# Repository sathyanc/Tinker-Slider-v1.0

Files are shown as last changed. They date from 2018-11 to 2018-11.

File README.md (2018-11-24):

# Tinker-Slider-v1.0

I have never seen a commercial slider. As a YouTuber, I wanted a Camera slider for taking b-rolls for my videos. So as a weekend project I started this project, and it took several weekends to complete. 

The following parts were used to build the single axis slider. 

1.M3 and M4 Machine Screw Box
2.Tripod Mount 1/4 Screw Adapter x 2
3.Tripod Mount Screw
4.Linear Motion Bearing x 4
5.Heat shrink tubes
6.Endstop modules x 2 
7.GT2 6mm, 2M timing belt
8.ESP32 NodeMcu Dev board
9.A4988 Stepper motor
10.Perf board
11.Male and Female Headers
12.SD1306 128x64 OLED display module
13.Belt tensioner spring
14.Rotary encoder
15.Linear, smooth rods 8mm, 500mm x 2
16.Wire Pipe 480mm
17.Linear Rail supports x 4

At the heart of the project sits the ESP32 microcontroller. Initially, I tried with ESP8266, but there were not enough pins, and then I tried with Arduino Pro Mini, but then the memory was minimal to use the LCD. 

The ESP32 runs Arduino Core. 

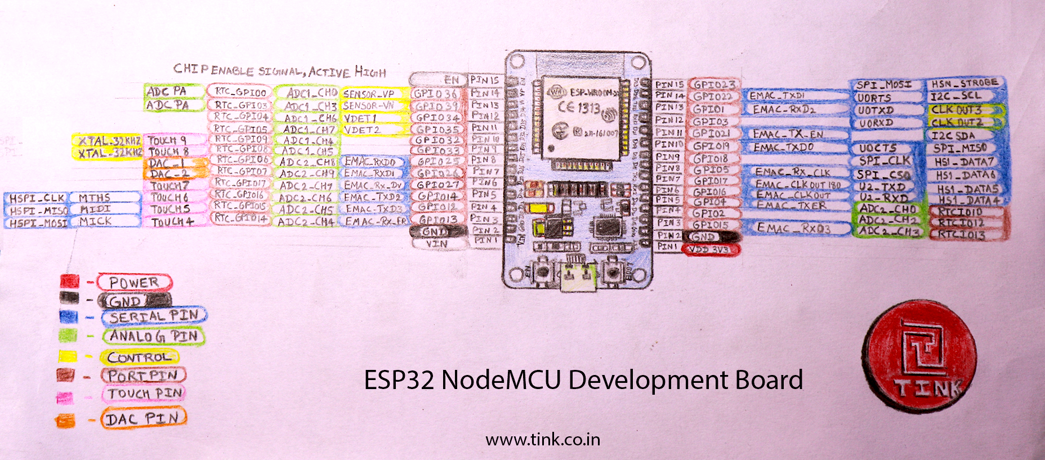
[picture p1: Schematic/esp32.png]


I used a 2 phase NEMA17 Hybrid motor that has a holding torque of 4000. The motor needs 1.7A per phase. It has a resolution of 1.8 degrees per step.  So to complete a single revolution, we need to step the motor 200 times. However, we need the resolution as low as 1 degree per step to be able to capture the super smooth moving time-lapse videos. 

The ESP32 Controls the stepper motor through the A4988 Stepper motor driver chip. This driver chip supports up to 1/16th  Microstepping mode which enables us to achieve rotational accuracy up to 0.0625degrees per step.

Awesome!

The SSD1306 0.96" OLED display module enables us to see an configure the display even under bright sunlight.

The Rotary Encoder can be used to precisely control the position of the motor and also as a selection tool for the menu. Several Modes like manual and automatic time-lapse, real-time control, tried and tested presets to shoot flowers, people, gadgets are supported.

Libraries required:
Accelstepper - https://github.com/adafruit/AccelStepper
Adafruit GFX - https://github.com/adafruit/Adafruit-GFX-Library
Adafruit SSD1306 - https://github.com/adafruit/Adafruit_SSD1306

References:
https://github.com/Wogified/Arduino-Motorized-Camera-Slider

To-Do:
WiFi Control by App / Custom Remote,
3 Axis Conversion,
CNC Milled Design

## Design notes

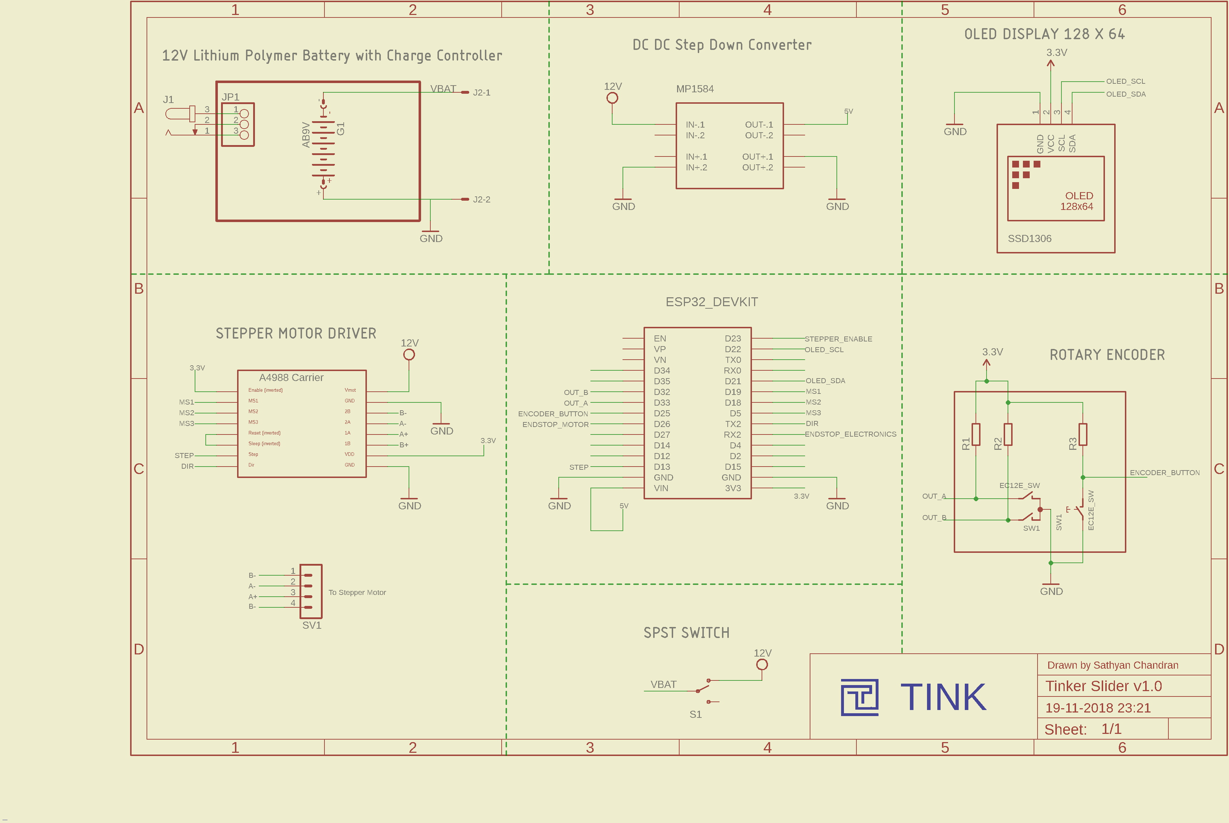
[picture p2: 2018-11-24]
Schematic/tinkerslider.png

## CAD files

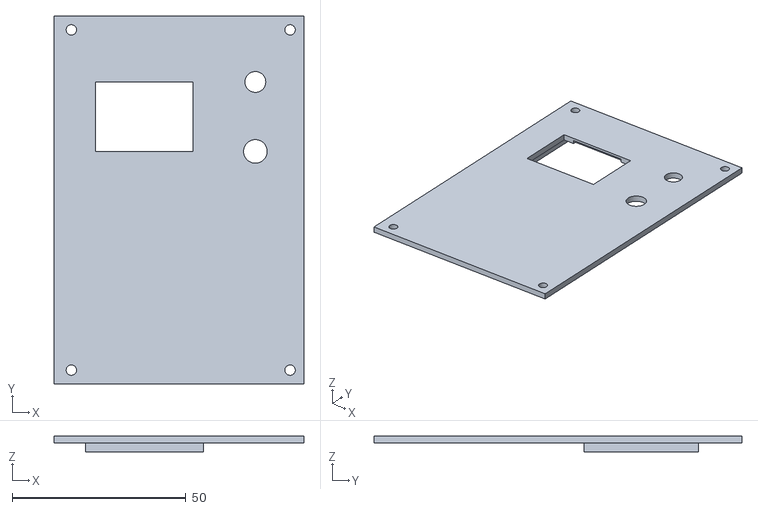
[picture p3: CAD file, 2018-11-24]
3D_Models/electronics lid v2.12.stl
72.0 x 106.0 x 4.50

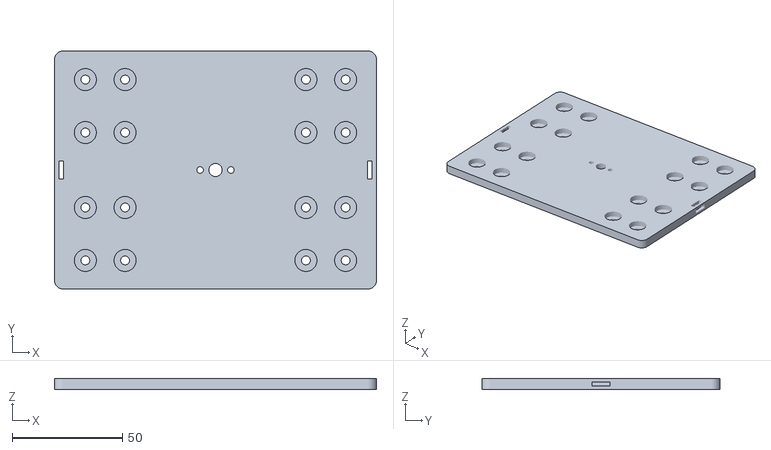
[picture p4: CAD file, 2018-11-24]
3D_Models/cam plate 4 bearings.stl
146.0 x 108.0 x 5.00

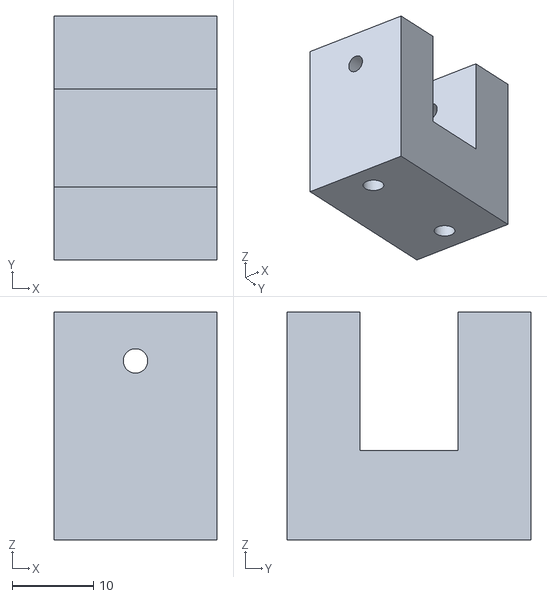
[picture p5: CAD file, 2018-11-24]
3D_Models/idle pulley holder.stl
20.0 x 30.0 x 28.0

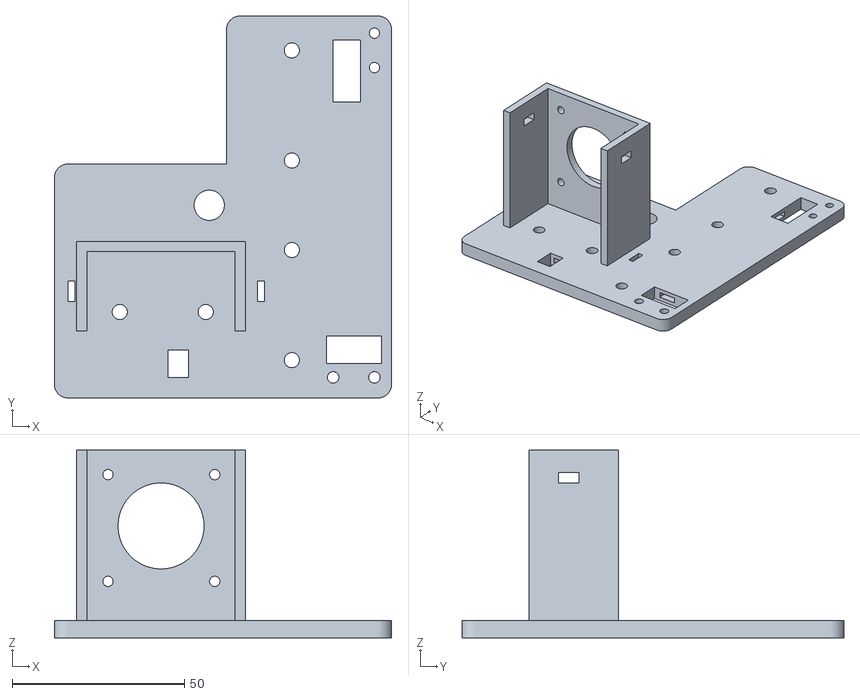
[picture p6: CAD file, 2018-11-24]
3D_Models/motor side base.stl
98.0 x 111.0 x 54.5

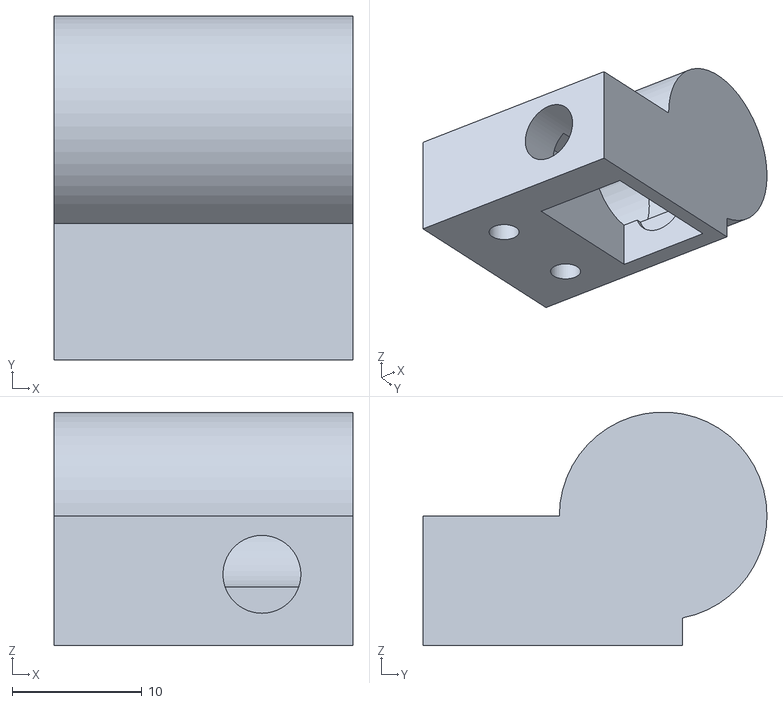
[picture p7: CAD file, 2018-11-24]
3D_Models/electronics_side_pipe_holder.stl
23.0 x 26.5 x 18.0

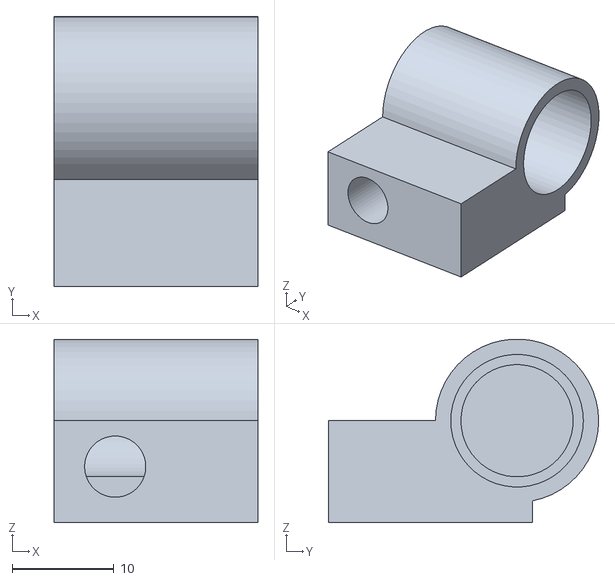
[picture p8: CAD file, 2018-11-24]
3D_Models/motor_side_pipe_holder.stl
20.0 x 26.5 x 18.0

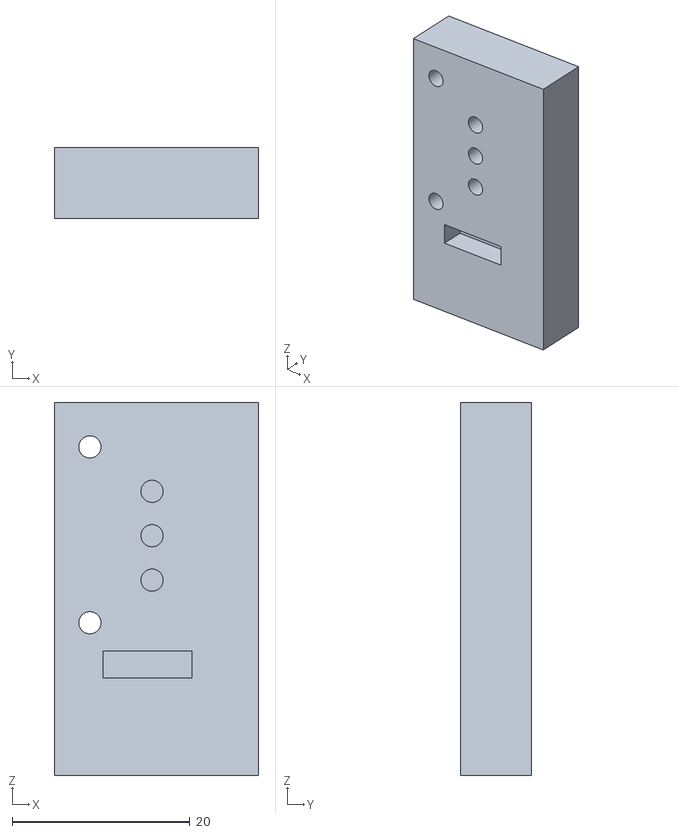
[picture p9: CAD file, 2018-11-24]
3D_Models/electronics endstop.stl
23.0 x 8.00 x 42.0

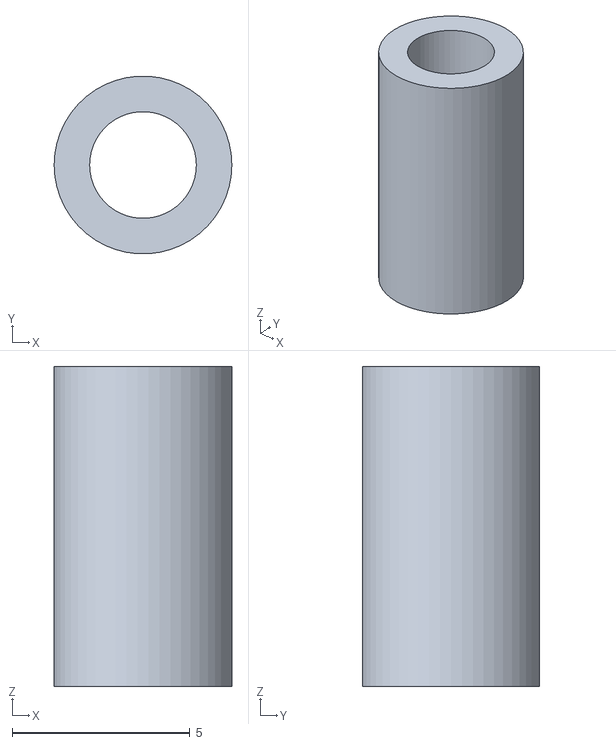
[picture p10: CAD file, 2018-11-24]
3D_Models/idle pulley bearing cylinder.stl
5.00 x 4.99 x 9.00

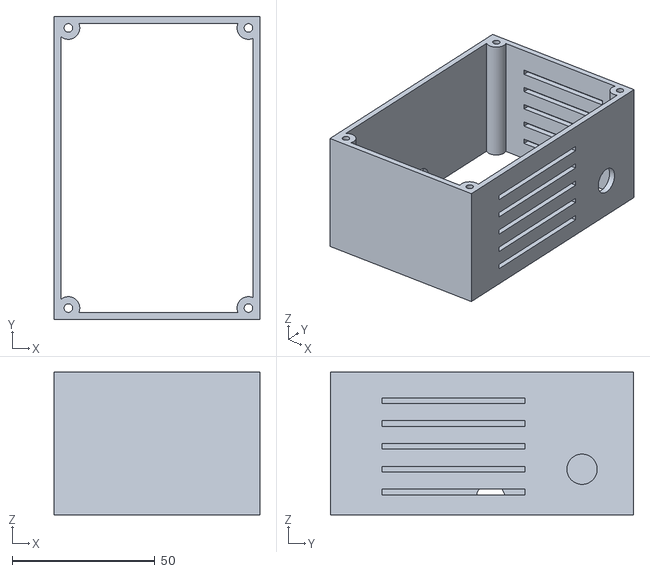
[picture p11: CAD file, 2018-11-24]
3D_Models/electronics box.stl
72.0 x 106.0 x 50.0

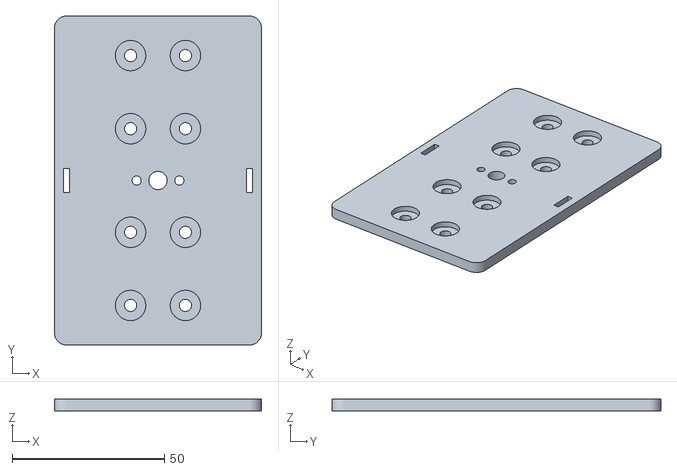
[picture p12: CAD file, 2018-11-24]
3D_Models/cam plate 2 bearings.stl
68.0 x 108.0 x 4.00

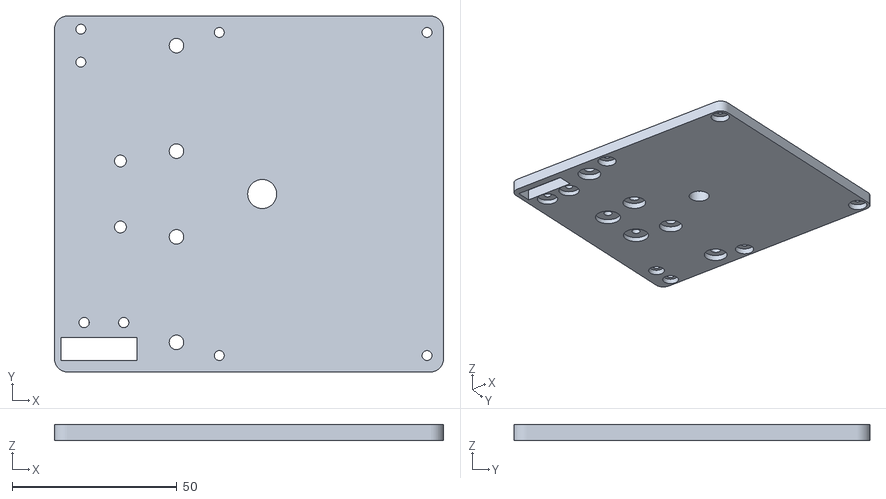
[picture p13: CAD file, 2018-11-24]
3D_Models/electronics base.stl
118.0 x 108.0 x 5.00

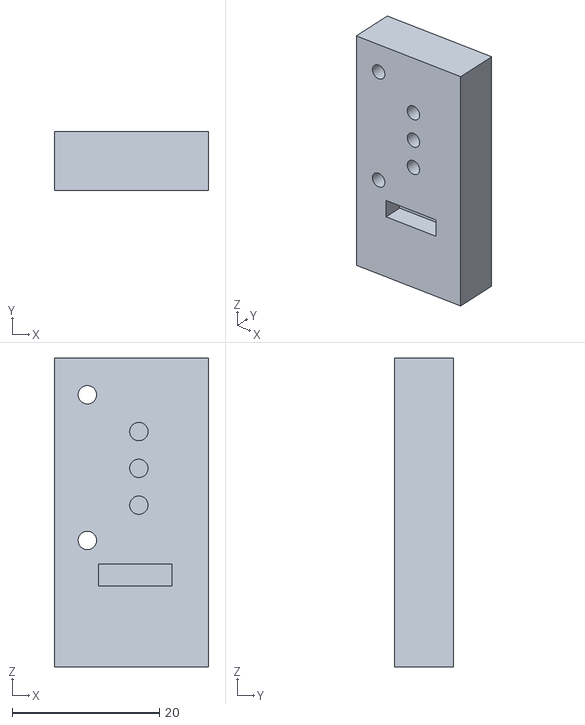
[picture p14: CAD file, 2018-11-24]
3D_Models/motor endstop.stl
21.0 x 8.00 x 42.0

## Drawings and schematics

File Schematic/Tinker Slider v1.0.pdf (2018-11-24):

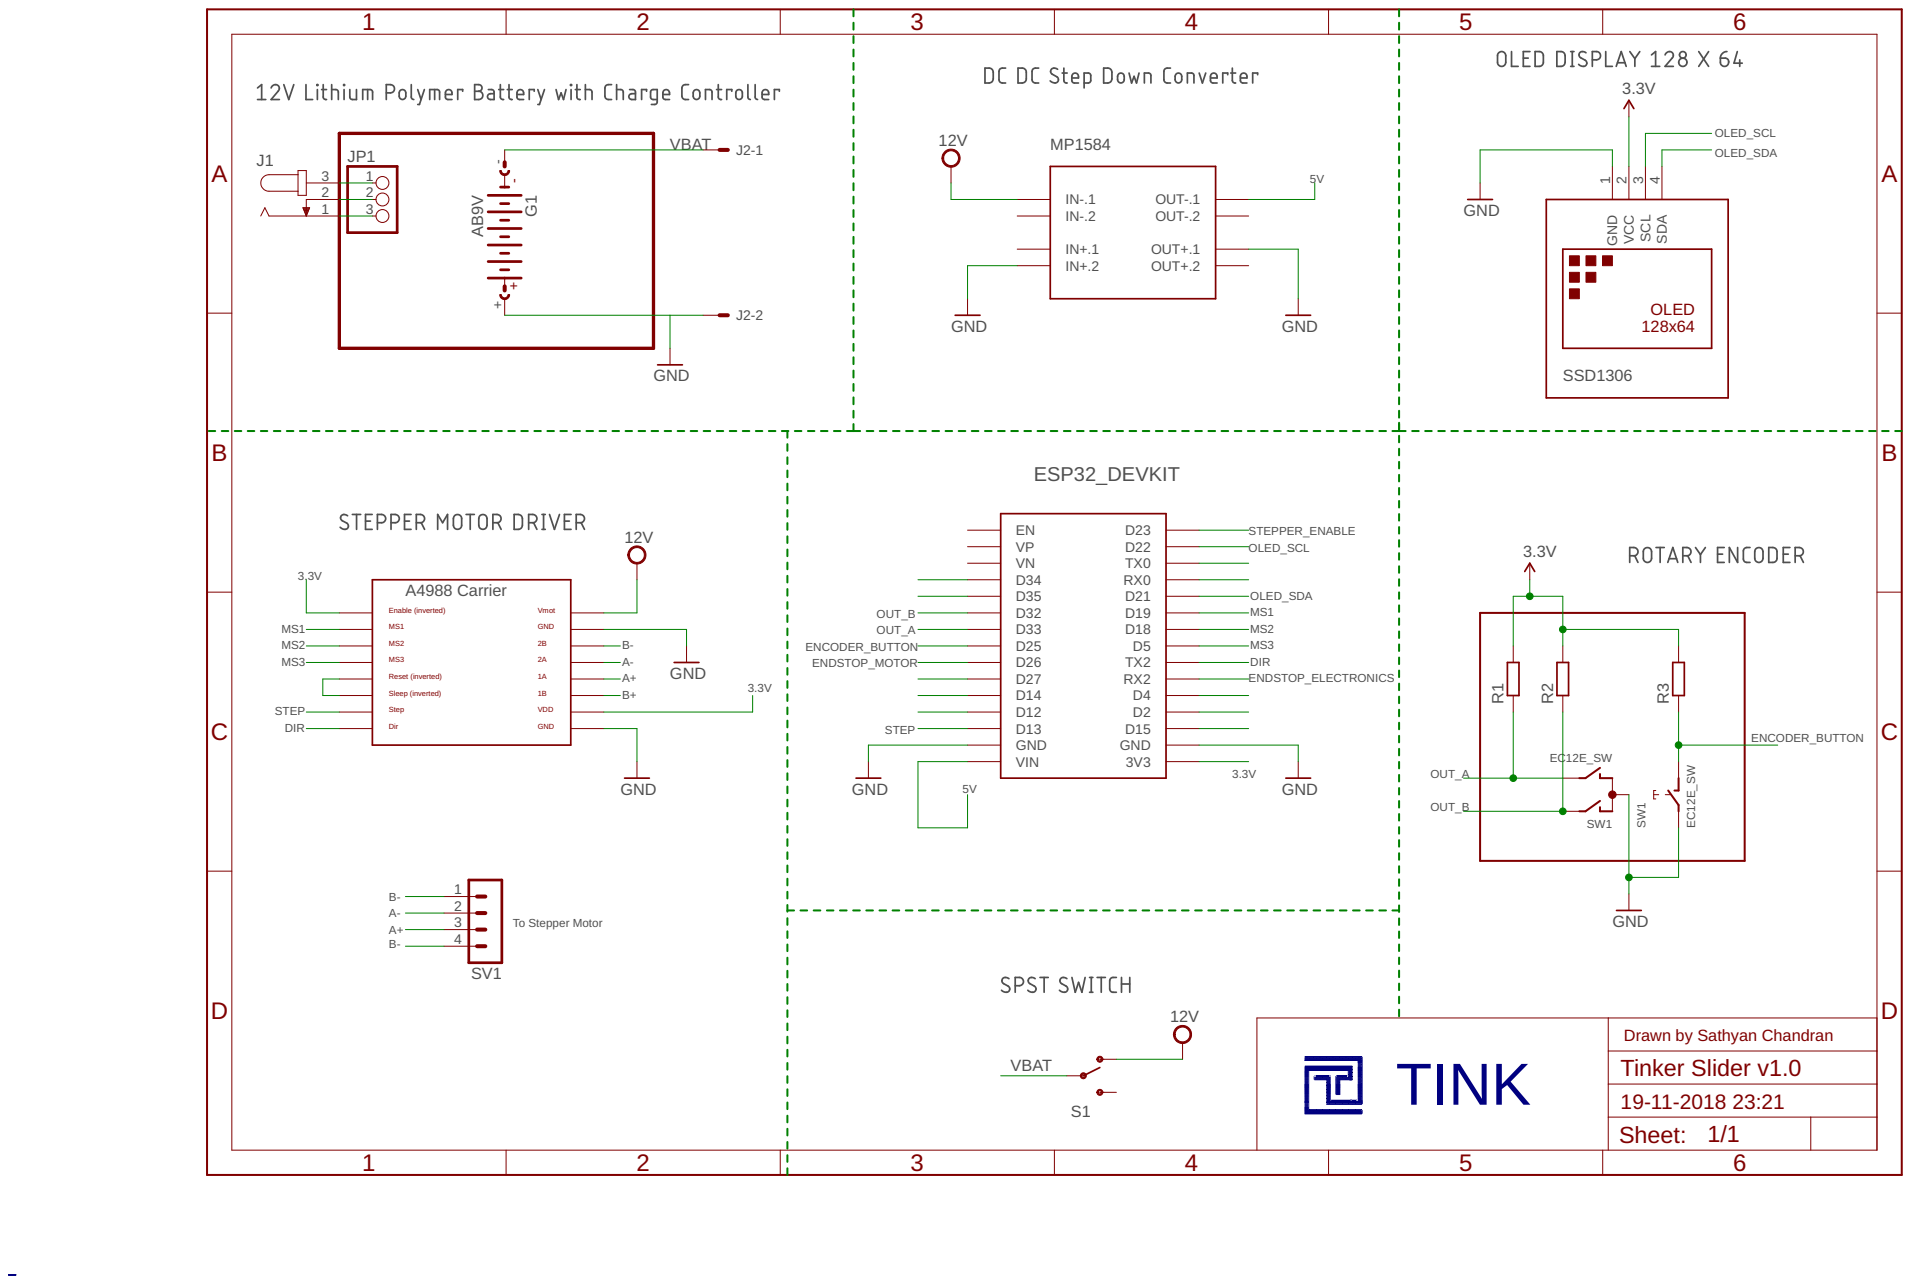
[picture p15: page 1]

TINK

Sheet: 1/1

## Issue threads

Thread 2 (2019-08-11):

New to ESP32, first project

diegotheslinger, 2019-08-11:
Hey, i've built a simple timelapse slider in the past based on atmel328, and was looking to expand some of its features.  Found your project and had an ESP32 laying around.  First time trying to use one.  I get it to compile and upload fine, but am getting errors in serial monitor.

Tinker Slider V1.0!!
Guru Meditation Error: Core  1 panic'ed (IntegerDivideByZero). Exception was unhandled.

I'm new to this, any tip on how to overcome this?  Maybe library issue?

Electoniclover, 2022-05-23:
I don't have a ti[ but i need help

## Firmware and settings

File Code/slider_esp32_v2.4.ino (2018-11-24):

// Runs on ESP32 Arduino. 
// To Do: Add WiFi controls


#include <SPI.h>
#include <Wire.h>
#include <Adafruit_GFX.h>
#include <Adafruit_SSD1306.h>
#include "AccelStepper.h" 

//Endstops
#define endstopMotor 26
#define endstopElectronics 16

//Stepper  
#define STEPPER_ENABLE 23
#define MS1 19
#define MS2 18
#define MS3 5
#define DIR 17
#define STEP 13

AccelStepper stepper(1, STEP, DIR); 

//Debug 
#define BAUD_RATE (9600)

//Display
#define OLED_RESET LED_BUILTIN 
#define LOGO16_GLCD_HEIGHT 16 
#define LOGO16_GLCD_WIDTH  16 

Adafruit_SSD1306 display(OLED_RESET);

//Encoder
#define encButton 25 
#define outA 33 
#define outB 32 

int outA_lastState,outA_currentState,counter=0;
int selection=1;
int numCount=1;
int encoderState;
int encoderLastState;  

volatile byte seqA = 0;
volatile byte seqB = 0;
volatile byte cnt1 = 0;
volatile byte cnt2 = 0;
volatile boolean right = false;
volatile boolean left = false;
volatile boolean encButtonStatus = false;


void IntCallback();
void EncButtonStatusInt();
void MainMenu(int selection);
void RealTime();
void FixedTime();
void Flowers();
void People();
void Review();
void Quick();
void TimeSlide(float tim);
void ManualTimeLapse();
void SlideRealTime(int def);
void TimeLapse();
void SetTimerTimeLapse();
void MainMenuFixedTime(int selection);
void MainMenu(int selection);


void setup() 
{
  Serial.begin(115200);
  Serial.println("Tinker Slider V1.0!!");

  //Status
  pinMode(LED_BUILTIN,OUTPUT);

  //Stepper Driver
  pinMode(STEP,OUTPUT); 
  pinMode(DIR,OUTPUT); 
  pinMode(STEPPER_ENABLE,OUTPUT);
  pinMode(MS1,OUTPUT);
  pinMode(MS2,OUTPUT);
  pinMode(MS3,OUTPUT);
  
  digitalWrite(STEPPER_ENABLE,LOW);
  
  // Set in 1/16th microstep mode
  digitalWrite(MS1,HIGH);
  digitalWrite(MS2,HIGH);
  digitalWrite(MS3,HIGH); 

  
  //Encoder
  pinMode(outA,INPUT_PULLUP);
  pinMode(outB,INPUT_PULLUP);
  pinMode(encButton,INPUT_PULLUP);
  digitalWrite(outA,HIGH);
  digitalWrite(outB,HIGH);
  digitalWrite(encButton,HIGH);

  //Interrupt Enable
  attachInterrupt(digitalPinToInterrupt(outA), IntCallback, CHANGE);
  attachInterrupt(digitalPinToInterrupt(outB), IntCallback, CHANGE);
  attachInterrupt(digitalPinToInterrupt(encButton), EncButtonStatusInt, CHANGE);
  
  //Endstop
  pinMode(endstopElectronics,INPUT_PULLUP);
  pinMode(endstopMotor,INPUT_PULLUP);
  digitalWrite(endstopElectronics,HIGH);
  digitalWrite(endstopMotor,HIGH);    
  
  //Display
  display.begin(SSD1306_SWITCHCAPVCC, 0x3C);  
  
  //Display the Tink splashscreen based on Adafruit GFX library
  display.display();  
  delay(1000);         
}

void loop() 
{ 
  MainMenu(ScrollSelection(3));  
}


void MainMenu(int selection)//main menu
{
  encButtonStatus=true;
  int numItems=3;

  Serial.println("Menu Select");
  display.clearDisplay();
  display.setTextSize(1);
  display.setTextColor(WHITE);
  display.setCursor(0,0);
  display.println("Tinker Slider v1.0");
  display.drawLine(0,15-1,127,15-1,WHITE);
  display.drawLine(0,16-1,127,16-1,WHITE);
  
  String MainMenu[] = {"1. RealTime","2. TimeLapse","3. FixedTime"};
  DisplayMenuSelection(numItems,MainMenu);
 
  
  if(encButtonStatus == false)
  {
    Serial.println("encButtonStatus Pressed");
    delay(500); // time delay to ensure encButtonStatus is released
    digitalWrite(encButton,HIGH);
    encButtonStatus=true;//set encButtonStatus state to false, otherwise it will remain true. it is toggle.
    switch(selection)
    {
      Serial.print("selection:");
      Serial.println(selection);
      case 1:
        RealTime();
        break;
      case 2:
        TimeLapse();  
        break;
      case 3:
        FixedTime();
        break;
      default:
        Serial.println("No such Menu");
        break;
    }      
  }
  
}


void MainMenuFixedTime(int selection)//main menu
{
  encButtonStatus=true;
  int numItems=4;
  
  display.clearDisplay();
  display.setTextSize(1);
  display.setTextColor(WHITE);
  display.setCursor(0,0);
  display.println("Fixed Time Mode");
  display.drawLine(0,15-1,127,15-1,WHITE);
  display.drawLine(0,16-1,127,16-1,WHITE);
  
  String MainMenu[] = {"1. Flowers ","2. People","3. Review","4. Quick!"};
  DisplayMenuSelection(numItems,MainMenu);

  //if the encoder encButtonStatus is pressed, then selection is made (through interrupts)
  if(encButtonStatus == false)
  {
    Serial.println("Button Pressed");
    delay(500); // time delay to ensure encButtonStatus is released
    digitalWrite(encButton,HIGH);
    encButtonStatus=true;  
    switch(selection)
    {
      Serial.print("selection:");
      Serial.println(selection);
      case 1:
        Flowers();    // Contains the tried and tested sliding time to capture flowers
        break;
      case 2:
        People();     // Contains the tried and tested sliding time to capture people
        break;
      case 3:
        Review();     // Contains the tried and tested sliding time to review products (Accelerated)
        break;
      case 4:
        Quick();      // A 5 sec quick slide!
        break;
      default:
        Serial.println("No such Menu");
        break;
    }      
  }
  
}



void SetTimerTimeLapse()
{
  
    int hr=0,mins=0,sec=0;
    char hrs[3],minutes[3],seconds[3];
    int timePlaceHolder = 0; 
    float timeVal = 0;
    
    // Prepare the display
    display.clearDisplay();
    display.setTextSize(1);
    display.setTextColor(WHITE);
    display.setCursor(0,0);
    
    display.println("Set the Timer!");
    display.setCursor(0,20);
    display.println("H : M : S");
    
    display.setTextColor(WHITE,BLACK);
    display.setCursor(0,36);

    //Display the time placeholders
    display.print(hr);
    display.print("   ");
    display.print(mins);
    display.print("   ");
    display.print(sec);

    display.setTextColor(BLACK,WHITE);
    display.setCursor(0,36);
    display.print("0");

    //Update the display
    display.display();
    
    encButtonStatus =true;
    counter = 0;
    encoderLastState = digitalRead(outA);

    while(1)
    {    
       encoderState = digitalRead(outA); // Reads current state of the outA
       if(encoderState != encoderLastState)
       { 
        if(timePlaceHolder==0)//hr
        {
        
         // clockwise if the outB state is different to the outA state
         if (digitalRead(outB) != encoderState)  hr++;
         else hr--;
         
         if(hr <=0) hr=0;  

         Serial.print("hr: ");
         Serial.println(hr);

         //Print the change on the display 
         sprintf((char*)hrs,"%-2d",hr);
         display.setTextColor(BLACK,WHITE);
         display.setCursor(0,36);
         display.print(hrs);
         
       }          

       if(timePlaceHolder==1)//Min
       {
         // clockwise if the outB state is different to the outA state
         if (digitalRead(outB) != encoderState) mins++;
         else mins--;
         
         if (mins <=0) mins =0;
                    
         Serial.print("mins: ");
         Serial.println(mins);
         
         //Print the change on the display 
         sprintf((char*)minutes,"%-2d",mins);
         display.setTextColor(BLACK,WHITE);
         display.setCursor(22,36);
         display.print(minutes);
       }

       
       if(timePlaceHolder==2)//Sec
       {
         // clockwise if the outB state is different to the outA state
         if (digitalRead(outB) != encoderState)  sec++;
         else  sec--;
         if (sec <= 0) sec=0;
         
         Serial.print("sec: ");
         Serial.println(sec);

         //Print the change on the display 
         sprintf((char*)seconds,"%-2d",sec);
         display.setTextColor(BLACK,WHITE);
         display.setCursor(44,36);
         display.print(seconds);
        }
        //Update the display
        display.display();    
       }    
       

       //Confirm the selection if the encoder encButtonStatus is pressed
       if(encButtonStatus== false)  
       {
        counter=0;
        delay(500); //Debounce

        //If hour Set, then highlight seconds placeholder 
        if(timePlaceHolder==0)
        {
          display.setTextColor(WHITE,BLACK);
          display.setCursor(0,36);
          display.print(hrs);

          display.setTextColor(BLACK,WHITE);
          display.setCursor(22,36);
          display.print("0");

        
        }
        //If mins Set, then highlight seconds placeholder
        else if(timePlaceHolder==1)
        {
         
          display.setTextColor(WHITE,BLACK);
          display.setCursor(22,36);
          display.print(minutes);

          display.setTextColor(BLACK,WHITE);
          display.setCursor(44,36);
          display.print("0");
        }

        // Time set
        else if(timePlaceHolder==2)
        {
          
          display.setTextColor(BLACK,WHITE);
          display.setCursor(44,36);
          display.print(seconds);
          display.display();    
          break;
        }
          
        timePlaceHolder++; 
       
        encoderState &= ~encoderState;    // Trigger the selection for the next option        
        encButtonStatus =true;
        digitalWrite(encButton,HIGH);
        display.display();                     
       }       
      }                       
      
      Serial.println("Time set");
      Serial.print("Hr:");
      Serial.print(hr);
      Serial.print("Mins");
      Serial.print(mins);
      Serial.print("Secs");
      Serial.print(sec);
      Serial.println(); 
        

      timeVal = sec + (mins * 60) + (hr*60*60); // calculate the time in secs
      Serial.println("Time in Seconds:");
      Serial.println(timeVal);

      // Bring the cam plate to home (Electronics Side endstop)
      homePosition();
      
      // Display the choosen Time in Seconds   
      display.clearDisplay();
      display.setTextSize(1);
      display.setTextColor(WHITE);
      display.setCursor(0,0);
      display.println("Timer Set!");
      display.drawLine(0,15-1,127,15-1,WHITE);
      display.drawLine(0,16-1,127,16-1,WHITE);
      display.setCursor(0,30);
      display.println("You have choosen");
      display.setCursor(12,40);
      display.print(timeVal);
      display.setCursor(68,40);
      display.print("Seconds");
      display.display();
    
      // Start the sliding for the timeVal seconds
      TimeSlide(timeVal);
}


// TimeLapse menu
void TimeLapse()
{
  selection =1;
  while(1)
  {  
    int selection = ScrollSelection(2);
    encButtonStatus=true;
    int numItems=2;
    
    Serial.println("Menu Select");
    display.clearDisplay();
    display.setTextSize(1);
    display.setTextColor(WHITE);
    display.setCursor(0,0);
    display.println("TimeLapse Modes");
    display.drawLine(0,15-1,127,15-1,WHITE);
    display.drawLine(0,16-1,127,16-1,WHITE);

    
    String MainMenu[] = {"1. Manual Adjust","2. Set Timer"};
    DisplayMenuSelection(numItems,MainMenu);
   
    
    if(encButtonStatus == false)
    {
      Serial.println("Button Pressed");
      delay(500); // debounce
      digitalWrite(encButton,HIGH);
      encButtonStatus=true;
      switch(selection)
      {
        Serial.print("selection:");
        Serial.println(selection);
        case 1:
          ManualTimeLapse();
          break;
        case 2:
          Serial.println("Set Timer");
          SetTimerTimeLapse();
          break;
      }      
    }
  }
}

// Manually adjust the time based on the encoder value
void ManualTimeLapse()
{
  Serial.println("In TimeLapse");
  
  homePosition();
  SlideRealTime(1);
  
}

// Used by Realtime slider 
void SlideRealTime(int def)
{  
  display.clearDisplay();
  display.setTextSize(1);
  display.setTextColor(WHITE);
  display.setCursor(0,0);
  display.println("Rotate the Knob Now!");
  display.setTextColor(WHITE,BLACK);
  display.setCursor(0,40);
  display.println("   Push to go Back!");
  display.display();
  delay(500);
  
  encoderLastState = digitalRead(outA); 
  stepper.enableOutputs(); 
  stepper.setMaxSpeed(4000);
  
  while(1)
  {
     encoderState = digitalRead(outA); 
     if (encoderState != encoderLastState)
     {     
       if (digitalRead(outB) != encoderState) 
         counter --;
       else 
         counter ++;
       Serial.print("Position: ");
       Serial.println(counter);
     } 
    
     
     stepper.setSpeed(def*counter);
     stepper.runSpeed(); 

     delayMicroseconds(1000);
           
     if(checkButtonStates() != 0)
      break;

      encoderLastState = encoderState; 
 } 
}


void Flowers()
{
  digitalWrite(MS1,HIGH);
  digitalWrite(MS2,HIGH);
  digitalWrite(MS3,HIGH); 
   
  homePosition();
  
  digitalWrite(MS1,HIGH);
  digitalWrite(MS2,HIGH);
  digitalWrite(MS3,LOW);
  
  stepper.setCurrentPosition(0);
  stepper.setMaxSpeed(1000);
  stepper.setAcceleration(500);
  stepper.moveTo(11200);  // Lets move upto 280mm which is required to complete the full slide
  
  while (stepper.currentPosition() != 11200) 
  {
     stepper.run();
     delayMicroseconds(1000);
     if(checkButtonStates() != 0)
      break;
  }
}

void People()
{
  digitalWrite(MS1,HIGH);
  digitalWrite(MS2,HIGH);
  digitalWrite(MS3,HIGH);
  homePosition();

  // Display Time in Seconds   
  display.clearDisplay();
  display.setTextSize(1);
  display.setTextColor(WHITE);
  display.setCursor(0,0);
  display.println("People Mode!");
  display.drawLine(0,15-1,127,15-1,WHITE);
  display.drawLine(0,16-1,127,16-1,WHITE);

  display.setCursor(0,30);
  display.println("Sliding Time");
  display.setCursor(28,40);
  display.print("10 Seconds");
  display.display();

  TimeSlide(10);
}

void Review()
{
  digitalWrite(MS1,HIGH);
  digitalWrite(MS2,HIGH);
  digitalWrite(MS3,HIGH);
  
  homePosition();
  
  digitalWrite(MS1,HIGH);
  digitalWrite(MS2,HIGH);
  digitalWrite(MS3,LOW);
  
  stepper.setCurrentPosition(0);
  stepper.setMaxSpeed(2000);
  stepper.setAcceleration(500);
  stepper.moveTo(11200);
  while (stepper.currentPosition() != 11200) 
  {
    stepper.run();
     
    if(checkButtonStates() != 0)
      break;
   
  }
  
}

void Quick()
{
  digitalWrite(MS1,HIGH);
  digitalWrite(MS2,HIGH);
  digitalWrite(MS3,HIGH);
  homePosition();
   
  TimeSlide(5);
}

void FixedTime()
{  
    selection=1;
    display.clearDisplay();
    Serial.println("In FixedTime");
    while(1)
      MainMenuFixedTime(ScrollSelection(4));     
}

void RealTime()
{
  Serial.println("In RealTime");
  homePosition();
   
  digitalWrite(MS1,HIGH);
  digitalWrite(MS2,HIGH);
  digitalWrite(MS3,HIGH);
  SlideRealTime(100);
}


void TimeSlide(float tim)
{
  float timeDelay=0;
  int microMode = 0;
  encButtonStatus=true;
  Serial.println("tim:");
  Serial.println(tim);
  
 
  // Anything greater than 23 seconds can have  1/16th microstepping 
  if(tim >=23)
  {
    Serial.println(">23");
    digitalWrite(MS1,HIGH);
    digitalWrite(MS2,HIGH);
    digitalWrite(MS3,HIGH);
    timeDelay = (tim*1000) /22521;
    microMode = 3200;
  }
  
  // 1/8th microstepping 
  if(tim < 23 && tim > 11)
  {    
    Serial.println("<23 >11");
    digitalWrite(MS1,HIGH);
    digitalWrite(MS2,HIGH);
    digitalWrite(MS3,LOW);
    timeDelay = (tim*1000) /11263;
    microMode = 1600;
  }

  //1/4th microstepping
  if(tim <=10)
  {
    Serial.println("<10");    
    digitalWrite(MS1,LOW);
    digitalWrite(MS2,HIGH);
    digitalWrite(MS3,LOW);
    timeDelay = (tim*1000) /5630;
    microMode = 800;
  }
  
  stepper.enableOutputs(); 
  stepper.setMaxSpeed(4000);
  stepper.setSpeed(4000);
  
  Serial.print("timeDelay");
  Serial.println(timeDelay);
  Serial.print("Micromode");
  Serial.println(microMode);
  int lastTime = millis();


  for(int i = 0; i < microMode *7; i++)
  {
     stepper.runSpeed(); 
     delayMicroseconds(1000*timeDelay);
    
     if(checkButtonStates() != 0)
      break;
     
  }
  Serial.println(millis() -lastTime);

}


// Interrupts
void IntCallback()
{
    // Read A and B signals
   
    boolean A_val = digitalRead(outA);
    boolean B_val = digitalRead(outB);

    // Record the A and B signals in seperate sequences
    seqA <<= 1;
    seqA |= A_val;
    
    seqB <<= 1;
    seqB |= B_val;
    
    // Mask the MSB four bits
    seqA &= 0b00001111;
    seqB &= 0b00001111;
    
    // Compare the recorded sequence with the expected sequence
    if (seqA == 0b00001001 && seqB == 0b00000011) {
      cnt1++;
      left = true;
      //Serial.print("L cnt1:");
      //Serial.println(cnt1);
      }
     
    if (seqA == 0b00000011 && seqB == 0b00001001) {
      cnt2++;
      right = true;
      //Serial.print("L cnt2:");
      //Serial.println(cnt2);
      }  
}

void EncButtonStatusInt()
{
  if(!digitalRead(encButton))  
  {
    encButtonStatus   = false;
    Serial.println("Button Status Changed");
  }
}    

int checkButtonStates()
{  
   if(digitalRead(endstopElectronics) == false)
   {  
    Serial.println("Electronics Endstop Triggered");
    stepper.setMaxSpeed(2000);
    stepper.setSpeed(500);      
    for(int k = 0 ;k <300;k++)
    {
      stepper.runSpeed();
      delay(2);
    }
    counter=0;
    return -1;
   }  
   
   if(digitalRead(endstopMotor) == false)
   {  
    Serial.println("Motor Endstop Triggered");
    stepper.setMaxSpeed(2000);
    stepper.setSpeed(-500);      
    for(int k = 0 ;k <300;k++)
    {
      stepper.runSpeed(); 
      delay(2);
    }
    counter=0;
    return -1;
   }  

   if(encButtonStatus== false)  
   {
    Serial.println("Button Pressed");
    encButtonStatus =true;
    digitalWrite(encButton,HIGH);
    return -1;     
   }
   return 0;
}


int ScrollSelection(int numRows) 
{
  if (left) 
  {
    left = false;
    selection--;
    if (selection==0) 
      selection=numRows;      
  }
  if (right) 
  {
    right = false;
    selection++;
    if (selection==numRows+1) 
      selection=1;      
  }  
  return selection;
}

//homes the system to the limit switch
void homePosition()
{
  digitalWrite(MS1,HIGH);
  digitalWrite(MS2,HIGH);
  digitalWrite(MS3,HIGH);
  delay(500);
  display.clearDisplay();
  display.setTextSize(1);
  display.setTextColor(WHITE);
  display.setCursor(0,20);
  display.println("Home position...");
  display.display(); 
  stepper.enableOutputs();
  stepper.setMaxSpeed(-4000);

  while(1)
  {
    if(digitalRead(endstopElectronics) == false)
      break; 
    stepper.setSpeed(-1000);      
    stepper.runSpeed();
    delayMicroseconds(1000);
  }
  stepper.setMaxSpeed(2000);
  stepper.setSpeed(500);      
  for(int k = 0 ;k <300;k++)
  {
    stepper.runSpeed();
    delay(2);
  }
}


//creates menu on the oled display
void DisplayMenuSelection(int numItems,String menu[])
{
  display.setTextSize(1);
  
  for(int i=1;i<numItems+1;i++)
  {
    display.setCursor(0, 10+i*10);    
    
    if (i==4 && selection==5 || selection == i)
      display.setTextColor(BLACK,WHITE);
    else 
      display.setTextColor(WHITE, BLACK);
    
    display.print(menu[i-1]);    
  }
  
  display.display(); 
}

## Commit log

2018-11-24 Added Schematic 3D files and Code
    [Tinker Slider v1.0.sch, cam plate 2 bearings.stl, cam plate 4 bearings.stl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]
2018-11-24 3D Files
    [electronics lid v2.12.stl]
2018-11-24 Added a hand drawn ESP32 pinout
    drawn by Jagadeesh Kanna
